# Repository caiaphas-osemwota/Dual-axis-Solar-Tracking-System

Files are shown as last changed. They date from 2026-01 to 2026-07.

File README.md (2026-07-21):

# Dual-axis-Solar-Tracking-System (in progress)
## Project Overview
This project has the ultimate goal to track directional light using multiple LDR sensors and an ESP32.  
It was developed step by step, starting with basic sensor validation and then using control centered design that can driving actuators based on light direction.  
The final goal is a dual-axis (azimuth + elevation) tracking system similar to solar trackers or camera gimbals.

---

## Current Firmware

The active ESP32 firmware for the dual-axis prototype is:

[`firmware/DualAxisSolarTracker/DualAxisSolarTracker.ino`](firmware/DualAxisSolarTracker/DualAxisSolarTracker.ino)

It reads four LDRs, filters the readings, calculates horizontal and vertical error, and commands independent azimuth and elevation servos. It requires the `ESP32Servo` library.

The sketches in [`archive/`](archive/) document earlier sensor and one-axis experiments. They are retained for reference and are not the firmware to upload for the dual-axis tracker.

### Project Layout

```text
firmware/DualAxisSolarTracker/  Active dual-axis ESP32 sketch
archive/                        Earlier experiments
Schematics/                     Electrical schematic sources and PDFs
3D Assemblies/                  Mechanical assembly model
```

### Uploading the Active Firmware

1. Install the ESP32 board package in Arduino IDE.
2. Install the `ESP32Servo` library through Library Manager.
3. Open `firmware/DualAxisSolarTracker/DualAxisSolarTracker.ino`.
4. Select the correct ESP32 board and serial port, then compile and upload.

> The dual-axis tracker remains a prototype. Verify the servo limits, polarity, wiring, and mechanical clearance before powering the servos.

---

## Prototype 1: Quadrant Light Sensing with Visual Feedback



**Goal:**  
Confirm LDR behavior and determine light direction using a simple output (LEDs).

**Design:**  
- Four LDRs in a square (quadrant) layout  
- Each LDR mapped to an LED (up, down, left, right) to display light intensity  

**What worked:**  
- Correctly identified the quadrant with the strongest light  
- Visual LED feedback simplified debugging and validation  

**Limitations:**  
- Limited-resolution directional output
- No continuous angle information  
- Not suitable for smooth actuator control  

**Reason for redesign:**  
Needed a way to convert light differences into a continuous control signal.

---

## Prototype 2: Differential Light Sensing for Azimuth Control



**Goal:**  
Enable smooth left–right tracking with continuous angular response.

**Design:**  
- Rearranged the LDRs into a “+” pattern  
- Calculated left–right sensor differences to control azimuth servo  

**Improvements over Prototype 1:**  
- Continuous response instead of limited directional input  
- Better suited for servo control  
- Clear separation between sensing and actuation logic  

**Observed limitations:**  
- Sensitivity to noise near neutral  
- Potential for oscillation without filtering or deadband  

**Outcome:**  
Established a functional 1-axis tracking system and laid groundwork for dual-axis expansion.

---

## Planned Prototype 3: Dual-Axis (Azimuth + Elevation) Tracking
**Goal:**  
Extend the system to full 2-axis directional tracking.

**Planned Design:**  
- Left–right differential → azimuth control  
- Top–bottom differential → elevation control  
- Drive two independent servos  

**Expected Challenges:**  
- Increased sensor noise sensitivity  
- Mechanical limits and servo dead zones  

**Planned Improvements:**  
- Deadband around neutral to reduce jitter  
- Low-pass filtering of ADC readings  
- Optional PID control for smoother convergence  

---

## Results and Observations
- Sensor layout strongly impacts control quality  
- Differential sensing enables proportional control  
- Iterative prototyping improved stability and reduced complexity  

---

## Future Improvements
- Implement full PID control on both axes  
- Improve mechanical rigidity and damping  
- Replace breadboard wiring with a custom PCB  
- Optimize sensor placement
- Integrate IMU

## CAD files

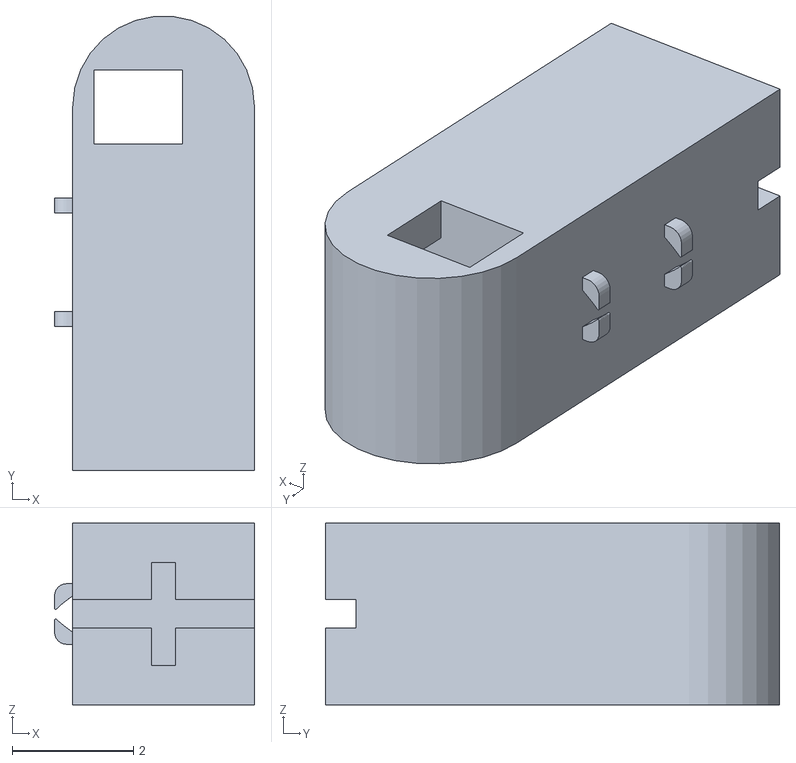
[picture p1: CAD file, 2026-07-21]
3D Assemblies/MotorAssembly_V2.obj
3.30 x 7.49 x 3.00

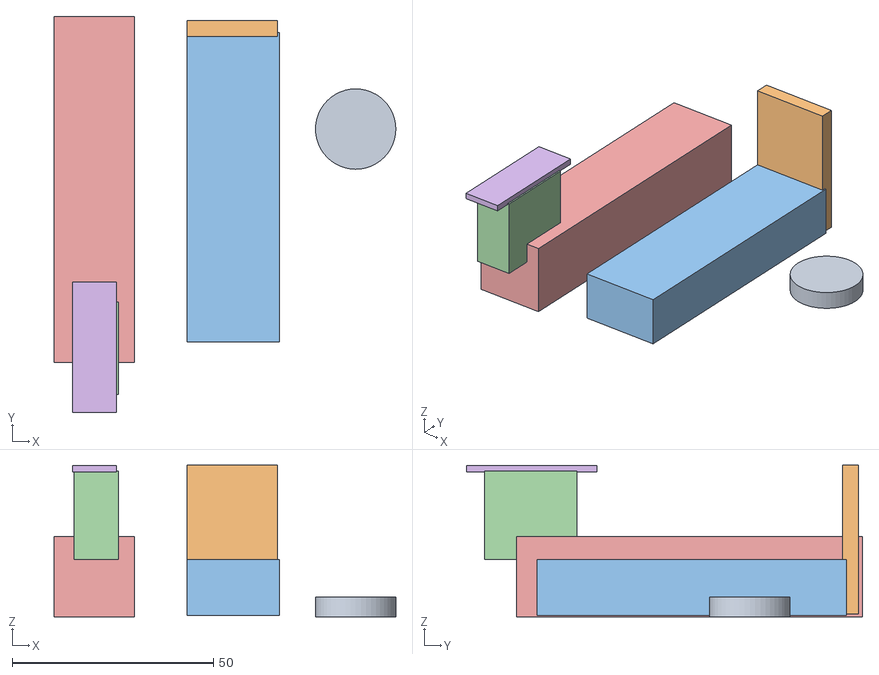
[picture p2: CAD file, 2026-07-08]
MotorAssembly3D.obj
85.0 x 98.5 x 37.8
obj_0
obj_1
obj_2
obj_3
obj_4
obj_5

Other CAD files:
3D Assemblies/MotorAssembly3D.obj

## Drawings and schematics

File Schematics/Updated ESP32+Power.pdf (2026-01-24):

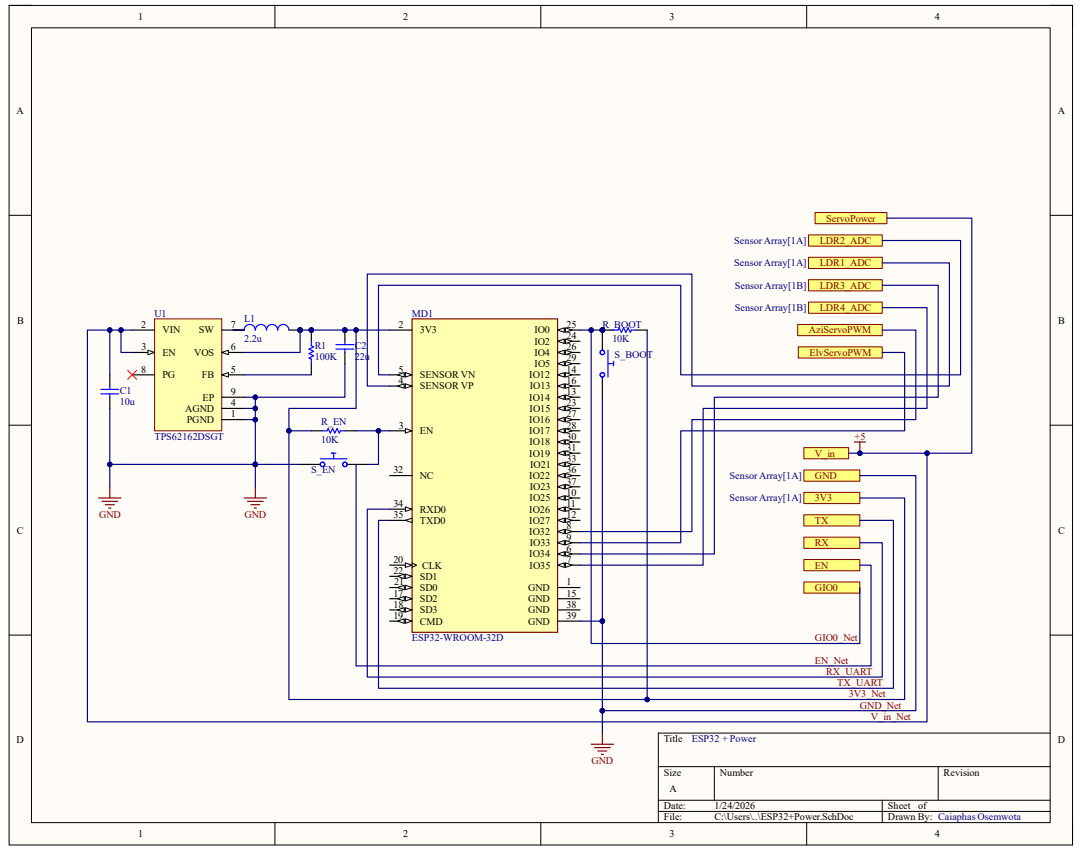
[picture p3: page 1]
Title; Size; Number; Revision; Date:; Sheet of; File:; C:\Users\..\ESP32+Power.SchDoc; Drawn By:; ESP32 + Power; SENSOR VN 5 SENSOR VP 4; RXD0 34; CLK 20; CMD 19; TXD0 35; GND; ESP32-WROOM-32D; S_BOOT; R_BOOT; Sensor Array[1A] 3V3; GIO0; ElvServoPWM; AziServoPWM; Sensor Array[1B] LDR4_ADC; Sensor Array[1B] LDR3_ADC; Sensor Array[1A] LDR1_ADC; Sensor Array[1A] LDR2_ADC; ServoPower; Caiaphas Osemwota; GIO0_Net; EN_Net RX_UART TX_UART 3V3_Net GND_Net V_in_Net; PGND; VIN 2; AGND; VOS; TPS62162DSGT

Sensor Array[1A] GND

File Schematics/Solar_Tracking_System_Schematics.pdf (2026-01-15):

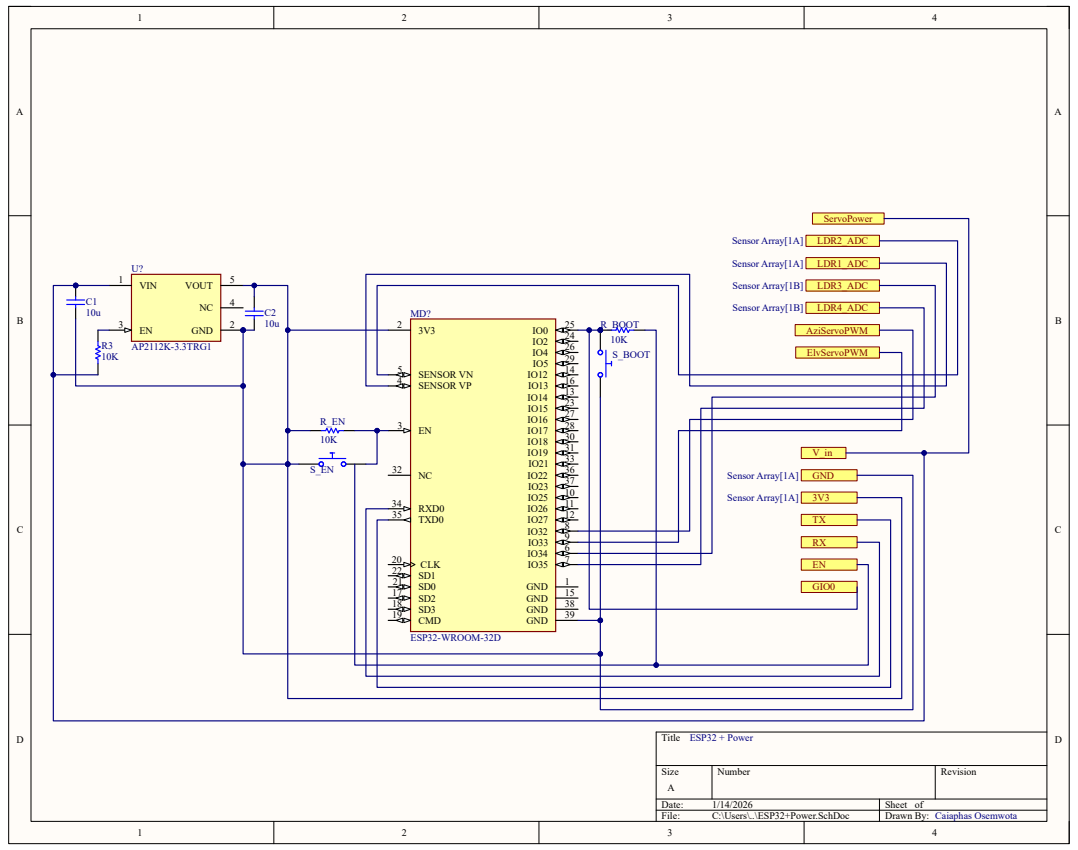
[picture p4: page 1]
Title; Size; Number; Revision; Date:; Sheet of; File:; C:\Users\..\ESP32+Power.SchDoc; Drawn By:; ESP32 + Power; SENSOR VN 5 SENSOR VP 4; RXD0 34; CLK 20; CMD 19; TXD0 35; GND; ESP32-WROOM-32D; VIN 1; VOUT; AP2112K-3.3TRG1; S_BOOT; R_BOOT; Sensor Array[1A]; GIO0; ElvServoPWM; AziServoPWM; Sensor Array[1B]; LDR4_ADC; LDR3_ADC; LDR1_ADC; LDR2_ADC; ServoPower; Caiaphas Osemwota

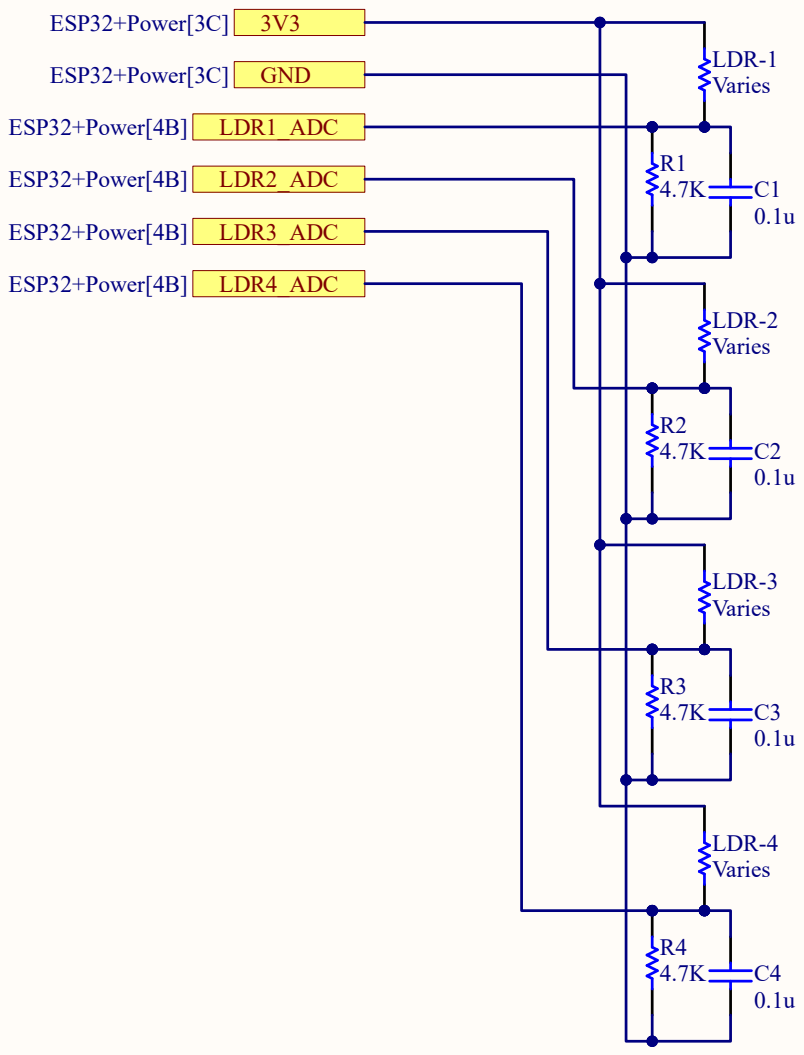
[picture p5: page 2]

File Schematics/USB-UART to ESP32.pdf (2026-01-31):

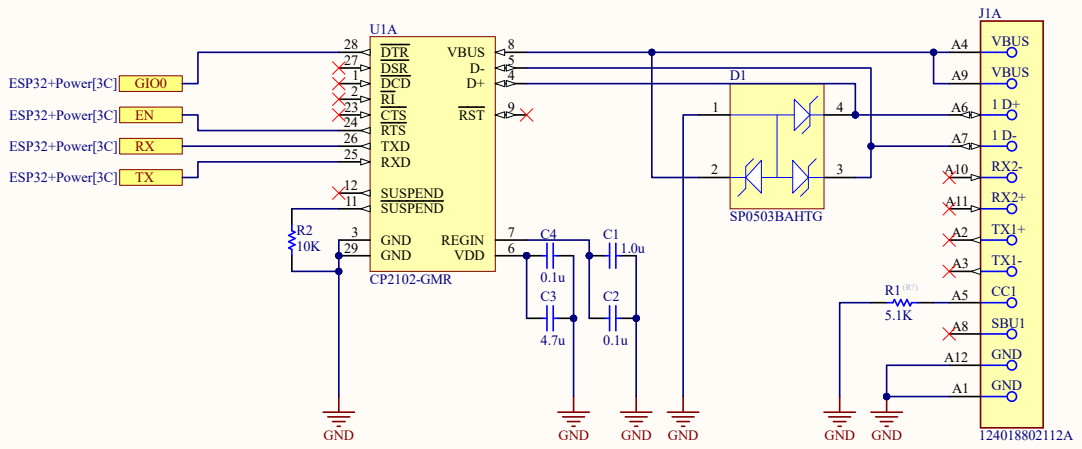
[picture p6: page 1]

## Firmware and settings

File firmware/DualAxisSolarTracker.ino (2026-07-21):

#include <ESP32Servo.h>

/*
  DualAxisSolarTracker

  Active firmware for the ESP32 dual-axis solar-tracking prototype.

  Hardware:
  - ESP32
  - Four LDRs: top, bottom, left, and right
  - Two servos: azimuth and elevation

  Dependency:
  - ESP32Servo

  The sketches in archive/ are earlier experiments and are not the active
  tracker firmware.
*/

//constants
const int AZSERVO_PIN  = 32; // Azimuth Servo control pin
const int ELVSERVO_PIN = 33; // Elevation Servo control pin
const int LDR_TOP    = 36; // LDR1 
const int LDR_LEFT   = 39; // LDR2
const int LDR_RIGHT  = 34; // LDR3
const int LDR_BOTTOM = 35; // LDR4
const float VREF     = 3.3; // ADC ref voltage
const int ADC_MAX    = 4095; // 12-bit ADC
const float DEADBAND = 0.15; // Min voltage diff to move
const int AZ_MIN  = 20; // Servo angle limits (min)
const int AZ_MAX  = 160; // Servo angle limits (max)
const int ELV_MIN = 40;
const int ELV_MAX = 120;
const int baseline_samples = 20; // # of taken samples to average
const int baseline_sampledelay = 10; // ms between samples

Servo azServo;
Servo elvServo;
int AzservoAngle = 90;
int ElvservoAngle = 90;

// Baselines
float baselineLeft  = 0;
float baselineRight = 0;
float baselineTop = 0;
float baselineBottom = 0;
float HorizontalBias = 0;
float VerticalBias = 0;

//EWA Filter
const float ALPHA = 0.2;
float filtLeft = 0, filtRight = 0, filtTop = 0, filtBottom = 0;
bool filtInit = false;

// PID Gains
float Kp_az = 50.0, Ki_az = 0.0, Kd_az = 0.0;
float Kp_el = 50.0, Ki_el = 0.0, Kd_el = 0.0;

// PID state
float azIntegral = 0, elvIntegral = 0;
float azPrevError = 0, elvPrevError = 0;

const float INTEGRAL_LIMIT = 50.0;
unsigned long lastLoopTime = 0;

float pidStep(float error, float &integral, float &prevError, float Kp, float Ki, float Kd, float dt) {
  if (abs(error) <= DEADBAND) {
    prevError = error;
    return NAN;
  }
  integral += error * dt;
  integral = constrain(integral, -INTEGRAL_LIMIT, INTEGRAL_LIMIT);
  float derivative = (error - prevError) / dt;
  prevError = error;
  return Kp * error + Ki * integral + Kd * derivative;
}

float readAveragedLDR (int pin) {
  long sum = 0;
  for (int i = 0; i < baseline_samples; i++) {
    sum += analogRead(pin);
    delay(baseline_sampledelay);
  }
  float avgRaw = sum / (float) baseline_samples;
  return avgRaw * VREF / ADC_MAX;
}

void setup() {
  Serial.begin(115200);
  azServo.attach(AZSERVO_PIN);
  elvServo.attach(ELVSERVO_PIN);
  azServo.write(AzservoAngle);
  elvServo.write(ElvservoAngle);
  delay(2000);
 // baseline voltages
  baselineLeft = readAveragedLDR(LDR_LEFT);
  baselineRight = readAveragedLDR(LDR_RIGHT);
  baselineTop = readAveragedLDR(LDR_TOP);
  baselineBottom = readAveragedLDR(LDR_BOTTOM);
// center bias
  HorizontalBias = baselineLeft - baselineRight;
  VerticalBias = baselineTop - baselineBottom;
  
  lastLoopTime = millis();

  Serial.println("Baseline:");
  Serial.print("Left: "); Serial.println(baselineLeft, 3);
  Serial.print("Right: "); Serial.println(baselineRight, 3);
  Serial.print("Top: "); Serial.println(baselineTop, 3);
  Serial.print("Bottom: "); Serial.println(baselineBottom, 3);
  Serial.print("Horizontal Bias: "); Serial.println(HorizontalBias, 3);
  Serial.print("Vertical Bias: "); Serial.println(VerticalBias, 3);
}

void loop() {
  unsigned long now = millis();
  float dt = (now - lastLoopTime) / 1000.0; // actual elapsed seconds
  if (dt <= 0.001) dt = 0.015;
  lastLoopTime = now;
  // Read LDRs
  float leftV_raw = analogRead(LDR_LEFT) * VREF / ADC_MAX;
  float rightV_raw = analogRead(LDR_RIGHT) * VREF / ADC_MAX;
  float topV_raw = analogRead(LDR_TOP) * VREF / ADC_MAX;
  float bottomV_raw = analogRead(LDR_BOTTOM) * VREF / ADC_MAX;
  
  if (!filtInit) {
  filtLeft = leftV_raw; filtRight = rightV_raw;
  filtTop = topV_raw; filtBottom = bottomV_raw;
  filtInit = true;
  }
  filtLeft += ALPHA * (leftV_raw - filtLeft);
  filtRight += ALPHA * (rightV_raw - filtRight);
  filtTop += ALPHA * (topV_raw - filtTop);
  filtBottom += ALPHA * (bottomV_raw - filtBottom);

  // Calculate error
  float horizontalerror = (filtLeft - filtRight) - HorizontalBias;
  float verticalerror = (filtTop - filtBottom) - VerticalBias;
  // Servo control with deadband and scaling
  
  float azOutput = pidStep(horizontalerror, azIntegral, azPrevError, Kp_az, Ki_az, Kd_az, dt);
  if (!isnan(azOutput)) {
    AzservoAngle = constrain(90 + int(azOutput), AZ_MIN, AZ_MAX);
  }

  float elvOutput = pidStep(verticalerror, elvIntegral, elvPrevError, Kp_el, Ki_el, Kd_el, dt);
  if (!isnan(elvOutput)) {
    ElvservoAngle = constrain(90 + int(elvOutput), ELV_MIN, ELV_MAX);
  }

// Write to servo
  azServo.write(AzservoAngle);
  elvServo.write(ElvservoAngle);
  
  // Debugging output

  Serial.print(" Filtered L: "); Serial.print(filtLeft, 2);
  Serial.print(" Filtered R: "); Serial.print(filtRight, 2);
  Serial.print(" Filtered T: "); Serial.print(filtTop, 2);
  Serial.print(" Filtered B: "); Serial.print(filtBottom, 2);

  Serial.print(" Raw L: "); Serial.print(leftV_raw, 2);
  Serial.print(" Raw R: "); Serial.print(rightV_raw, 2);
  Serial.print(" Raw T: "); Serial.print(topV_raw, 2);
  Serial.print(" Raw B: "); Serial.print(bottomV_raw, 2);

  Serial.print(" Horizontal Diff: "); Serial.print(horizontalerror, 3);
  Serial.print(" Vertical Diff: "); Serial.print(verticalerror, 3);
  Serial.print(" Azimuth Servo: "); Serial.println(AzservoAngle);
  Serial.print(" Elevation Servo: "); Serial.println(ElvservoAngle);  

  delay(15); // update frequency around 66 Hz
}

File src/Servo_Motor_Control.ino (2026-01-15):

#include <ESP32Servo.h>

//constants
const int SERVO_PIN  = 32; // Servo control pin
const int LDR_TOP    = 36; // LDR1 
const int LDR_LEFT   = 39; // LDR2
const int LDR_RIGHT  = 34; // LDR3
const int LDR_BOTTOM = 35; // LDR4
const float VREF     = 3.3; // ADC ref voltage
const int ADC_MAX    = 4095; // 12-bit ADC
const float DEADBAND = 0.15; // Min voltage diff to move
const float SCALE    = 150.0; // Scaling for servo response
const int SERVO_MIN  = 20; // Servo angle limits (min)
const int SERVO_MAX  = 160; // Servo angle limits (max)
Servo azServo;
int servoAngle = 90;

// Baselines
float baselineLeft  = 0;
float baselineRight = 0;
float centerBias    = 0;

void setup() {
  Serial.begin(115200);
  azServo.attach(SERVO_PIN);
  azServo.write(servoAngle);
  delay(2000);
 // baseline voltages
  baselineLeft  = analogRead(LDR_LEFT)  * VREF / ADC_MAX;
  baselineRight = analogRead(LDR_RIGHT) * VREF / ADC_MAX;
// center bias
  centerBias = baselineLeft - baselineRight;
  Serial.println("Baseline:");
  Serial.print("Left: "); Serial.println(baselineLeft, 3);
  Serial.print("Right: "); Serial.println(baselineRight, 3);
  Serial.print("Bias: "); Serial.println(centerBias, 3);
}
void loop() {
  // Read LDRs
  float leftV  = analogRead(LDR_LEFT)  * VREF / ADC_MAX;
  float rightV = analogRead(LDR_RIGHT) * VREF / ADC_MAX;
  // Calculate error
  float error = (leftV - rightV) - centerBias;
  // Servo control with deadband and scaling
  if (abs(error) <= DEADBAND) {
    // Centered: snap to 90°
    servoAngle = 90;
  } else {
    servoAngle = 90 + int(error * SCALE);
  }
// Constrain servo angle
  servoAngle = constrain(servoAngle, SERVO_MIN, SERVO_MAX);
// Write to servo
  azServo.write(servoAngle);
  // Debugging output
  Serial.print("L: "); Serial.print(leftV, 2);
  Serial.print(" R: "); Serial.print(rightV, 2);
  Serial.print(" Diff: "); Serial.print(error, 3);
  Serial.print(" Servo: "); Serial.println(servoAngle);
  delay(15); // update frequency around 66 Hz
}

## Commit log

2026-01-07 Rename IMG_7137 2.jpg to images/Prototype_Sensor_Array
2026-01-15 Rename Sensor Array.SchDoc to Schematics/Sensor Array.SchDoc
    [Sensor Array.SchDoc]
2026-01-15 Update and rename SolarTracker_ESP32.PrjPcb to Schematics/SolarTracker_ESP32.PrjPcb
    [SolarTracker_ESP32.PrjPcb]
2026-01-15 Update and rename Prototpye2_Updated_Sensor_Array_With_Single_Servo_Control to Prototype2_Updated_Sensor_Array_With_Single_Servo_Control
2026-01-24 Rename ESP32+PowerPDF.pdf to Schematics/Updated ESP32+Power.pdf
2026-01-31 Add USB-UART Conversion Schematic
2026-01-31 Rename USB-UART to ESP32.pdf to Schematics/USB-UART to ESP32.pdf
2026-05-16 Add new updated motor control code
2026-07-08 Added Updated Motor Control File
    With added EWA filtering, and PID Tuning (implemented tuning variables have not been set yet)
2026-07-08 Added 3D assembly files
    First prototype assembly for 3D printing
    [MotorAssembly3D.obj]
2026-07-08 Create 3D Assemblies
    For 3D motor assembly designs
2026-07-08 Update and rename MotorAssembly3D.obj to 3D Assembly/MotorAssembly3D.obj
    [MotorAssembly3D.obj]
2026-07-21 Add files via upload
    Adapted 3D print based on difficulties with first print
    [MotorAssembly_V2.obj]
